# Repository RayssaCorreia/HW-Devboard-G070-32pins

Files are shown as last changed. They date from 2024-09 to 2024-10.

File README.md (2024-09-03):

# Devboard-G070-32pins
Jornada de desenvolvimento  

### Softwares, ferramentas e tecnologias utilizadas para o projeto

- [Git](https://git-scm.com/) - Controlamento de versionamento 
- [Github](https://github.com/) - Compartilhamento do Projeto 
- [Kicad](https://docs.kicad.org/) - Software de desenvolvimento da PCB 
- [STM32 Cube IDE](https://www.st.com/en/development-tools/stm32cubeide.html) - Software de programação
- [Arduino](https://docs.arduino.cc/hardware/uno-rev3/) - Exemplos e talves gravação via a sua IDE
- [Flatcom](http://flatcam.org/manual/installation.html#linux)
- [CNC Router 3018 Pro 200W](https://router66.com.br/produto/cnc-router-3018-pro-200w/) - maquina para prototipagem da placa
### Comparação entre os pinos do Arduino Uno e o micro stm32g070

### Arduino
- Analog pins 

  | Pin | Function    | Type           | Description                 |
  |-----|-------------|----------------|-----------------------------|
  | 1   | NC          | NC             | Not connected               |
  | 2   | IOREF       | IOREF          | Reference for digital logic V - connected to 5V |
  | 3   | Reset       | Reset          | Reset                       |
  | 4   | +3V3        | Power          | +3V3 Power Rail             |
  | 5   | +5V         | Power          | +5V Power Rail              |
  | 6   | GND         | Power          | Ground                      |
  | 7   | GND         | Power          | Ground                      |
  | 8   | VIN         | Power          | Voltage Input               |
  | 9   | A0          | Analog/GPIO    | Analog input 0 / GPIO       |
  | 10  | A1          | Analog/GPIO    | Analog input 1 / GPIO       |
  | 11  | A2          | Analog/GPIO    | Analog input 2 / GPIO       |
  | 12  | A3          | Analog/GPIO    | Analog input 3 / GPIO       |
  | 13  | A4/SDA      | Analog input/I2C | Analog input 4 / I2C Data line |
  | 14  | A5/SCL      | Analog input/I2C | Analog input 5 / I2C Clock line |

- Digital pins 

  | Pin | Function        | Type             | Description                                  |
  |-----|-----------------|------------------|----------------------------------------------|
  | 1   | D0              | Digital/GPIO     | Digital pin 0 / GPIO                         |
  | 2   | D1              | Digital/GPIO     | Digital pin 1 / GPIO                         |
  | 3   | D2              | Digital/GPIO     | Digital pin 2 / GPIO                         |
  | 4   | D3              | Digital/GPIO     | Digital pin 3 / GPIO                         |
  | 5   | D4              | Digital/GPIO     | Digital pin 4 / GPIO                         |
  | 6   | D5              | Digital/GPIO     | Digital pin 5 / GPIO                         |
  | 7   | D6              | Digital/GPIO     | Digital pin 6 / GPIO                         |
  | 8   | D7              | Digital/GPIO     | Digital pin 7 / GPIO                         |
  | 9   | D8              | Digital/GPIO     | Digital pin 8 / GPIO                         |
  | 10  | D9              | Digital/GPIO     | Digital pin 9 / GPIO                         |
  | 11  | SS              | Digital SPI      | Chip Select                                  |
  | 12  | MOSI            | Digital SPI1     | Main Out Secondary In                        |
  | 13  | MISO            | Digital SPI      | Main In Secondary Out                        |
  | 14  | SCK             | Digital SPI      | Serial clock output                          |
  | 15  | GND             | Power            | Ground                                       |
  | 16  | AREF            | Digital          | Analog reference voltage                     |
  | 17  | A4/SD4          | Digital          | Analog input 4 / I2C Data line (duplicated)  |
  | 18  | A5/SD5          | Digital          | Analog input 5 / I2C Clock line (duplicated) |

### [STMG070KBT6](https://www.st.com/resource/en/datasheet/stm32g070rb.pdf)

| Pin Number | Pin Name (function upon reset) | Alternate Functions |
|---|---|---|
| 1 | PB9 | IR_OUT, TIM17_CH1, USART3_RX, SPI2_NSS, I2C1_SDA, EVENTOUT |
| 2 | PC14- OSC32_IN (PC14) | TIM1_BKIN2 |
| 3 | PC15- OSC32_OUT (PC15) | OSC32_EN, OSC_EN, TIM15_BKIN |
| 4 | VDD/VDDA | - |
| 5 | VSS/VSSA | - |
| 6 | NRST | - |
| 7 | PA0 | SPI2_SCK, USART2_CTS, USART4_TX |
| 8 | PA1 | SPI1_SCK/I2S1_CK, USART2_RTS_DE_CK, USART4_RX |
| 9 | PA2 | SPI1_MOSI/I2S1_SD, USART2_TX, TIM15_CH1 |
| 10 | PA3 | SPI2_MISO, USART2_RX, TIM15_CH2, EVENTOUT |
| 11 | PA4 | SPI1_NSS/I2S1_WS, SPI2_MOSI, TIM14_CH1, EVENTOUT |
| 12 | PA5 | SPI1_SCK/I2S1_CK, USART3_TX, EVENTOUT |
| 13 | PA6 | SPI1_MISO/I2S1_MCK, TIM3_CH1, TIM1_BKIN, USART3_CTS, TIM16_CH1 |
| 14 | PA7 | SPI1_MOSI/I2S1_SD, TIM3_CH2, TIM1_CH1N, TIM14_CH1, TIM17_CH1 |
| 15 | PB0 | SPI1_NSS/I2S1_WS, TIM3_CH3, TIM1_CH2N, USART3_RX |
| 16 | PB1 | TIM14_CH1, TIM3_CH4, TIM1_CH3N, USART3_RTS_DE_CK, EVENTOUT |
| 17 | PB2 | SPI2_MISO, USART3_TX, EVENTOUT |
| 18 | PA8 | MCO, SPI2_NSS, TIM1_CH1, EVENTOUT |
| 19 | PA9 | MCO, USART1_TX, TIM1_CH2, SPI2_MISO, TIM15_BKIN, I2C1_SCL, EVENTOUT |
| 20 | PC6 | TIM3_CH1 |
| 21 | PA10 | SPI2_MOSI, USART1_RX, TIM1_CH3, TIM17_BKIN, I2C1_SDA, EVENTOUT |
| 22 | PA11 | SPI1_MISO/I2S1_MCK, USART1_CTS, TIM1_CH4, TIM1_BKIN2, I2C2_SCL |
| 23 | PA12 | SPI1_MOSI/I2S1_SD, USART1_RTS_DE_CK, TIM1_ETR, I2S_CKIN, I2C2_SDA |
| 24 | PA13 | SWDIO, IR_OUT, EVENTOUT |
| 25 | PA14-BOOT0 | SWCLK, USART2_TX, EVENTOUT |
| 26 | PA15 | SPI1_NSS/I2S1_WS, USART2_RX, USART4_RTS_DE_CK, USART3_RTS_DE_CK, EVENTOUT |
| 27 | PB3 | SPI1_SCK/I2S1_CK, TIM1_CH2, USART1_RTS_DE_CK, EVENTOUT |
| 28 | PB4 | SPI1_MISO/I2S1_MCK, TIM3_CH1, USART1_CTS, TIM17_BKIN, EVENTOUT |
| 29 | PB5 | SPI1_MOSI/I2S1_SD, TIM3_CH2, TIM16_BKIN, I2C1_SMBA |
| 30 | PB6 | USART1_TX, TIM1_CH3, TIM16_CH1N, SPI2_MISO, I2C1_SCL, EVENTOUT |
| 31 | PB7 | USART1_RX, SPI2_MOSI, TIM17_CH1N, USART4_CTS, I2C1_SDA, EVENTOUT |
| 32 | PB8 | SPI2_SCK, TIM16_CH1, USART3_TX, TIM15_BKIN, I2C1_SCL, EVENTOUT |

# 

<table>
<thead>
  <tr>
    <th colspan="2">Arduino</th>
    <th colspan="2">Stm32G070</th>
  </tr>
  <tr>
    <td>Bit 0</td>
    <td>Bit 1</td>
    <td>Bit 2</td>
    <td>Bit 3</td>
    <td>Bit 4</td>
    <td>Bit 5</td>
    <td>Bit 6</td>
    <td>Bit 7</td>
    <td>Bit 8</td>
    <td>Bit 9</td>
    <td>Bit 10</td>
    <td>Bit 11</td>
    <td>Bit 12</td>
    <td>Bit 13</td>
    <td>Bit 14</td>
    <td>Bit 15</td>
  </tr>
</thead>
<tbody>
  <tr>
    <th colspan="8">ff</th>
    <th colspan="8">01</th>
  </tr>
  <tr>
    <td colspan="9">        Heading GPS</td>
    <td> Acc</td>
    <td> Jammer</td>
    <td> GPS Status</td>
    <td> Power Supply Status</td>
    <td> Critical Battery</td>
    <td> Ignition</td>
    <td> Speed Value</td>
  </tr>
</tbody>
</table>

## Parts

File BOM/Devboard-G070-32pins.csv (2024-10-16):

Reference | Value | Datasheet | Footprint | Qty | DNP
BZ1 | Buzzer | ~ |  | 1
C2,C7,C11,C12 | 20pF | ~ |  | 4
C3,C5,C8 | 100nf | ~ |  | 3
C4 | 100uF | ~ |  | 1
C6 | 10uF | ~ |  | 1
C9,C10 | 100nF | ~ |  | 2
D1 | LED_RGB | ~ |  | 1
D2,D5 | TVS 5.0 | ~ |  | 2
D3 | LED_Red | ~ |  | 1
D4 | B5819W | ~ |  | 1
F1 | 1A | ~ |  | 1
IC1 | MC3479 | http://www.memsic.com/uploadfiles/2020/08/20200827164636363.pdf | MC3479 | 1
J1 | Conn_01x04 | ~ |  | 1
J2 | USB_C_Receptacle_USB2.0_16P | https://www.usb.org/sites/default/files/documents/usb_type-c.zip |  | 1
J4 | Conn_01x05 | ~ |  | 1
J5,J8 | Conn_01x08 | ~ |  | 2
J6 | Conn_01x06 | ~ |  | 1
J7 | Conn_01x10 | ~ |  | 1
J9,J11 | Conn_02x18 | ~ | -- mixed values -- | 2
JP1,JP2,JP3,JP4,JP8,JP9 | 2_Open | ~ | TestPoint:TestPoint_2Pads_Pitch5.08mm_Drill1.3mm | 6
JP10 | ~ | ~ | TestPoint:TestPoint_2Pads_Pitch5.08mm_Drill1.3mm | 1
Q3 | 2N7002H | http://www.diodes.com/assets/Datasheets/2N7002H.pdf | Package_TO_SOT_SMD:SOT-23 | 1
R1,R2,R3 | 1K | ~ |  | 3
R4,R5 | 1k | ~ |  | 2
R6,R21 | 100 | ~ |  | 2
R7,R9,R10,R13,R14 | 4.7k | ~ |  | 5
R8 | 1M | ~ |  | 1
R11,R12 | 0 | ~ |  | 2
R20 | 100K | ~ |  | 1
SW3,SW4 | SW_MEC_5E | http://www.apem.com/int/index.php?controller=attachment&id_attachment=1371 |  | 2
U2 | TLV70233_SOT23-5 | http://www.ti.com/lit/ds/symlink/tlv702.pdf | Package_TO_SOT_SMD:SOT-23-5 | 1
U3 | STM32G070KBTx | https://www.st.com/resource/en/datasheet/stm32g070kb.pdf | Package_QFP:LQFP-32_7x7mm_P0.8mm | 1
Y1 | 32.768Khz | ~ |  | 1
Y2 | 8Mhz | ~ |  | 1

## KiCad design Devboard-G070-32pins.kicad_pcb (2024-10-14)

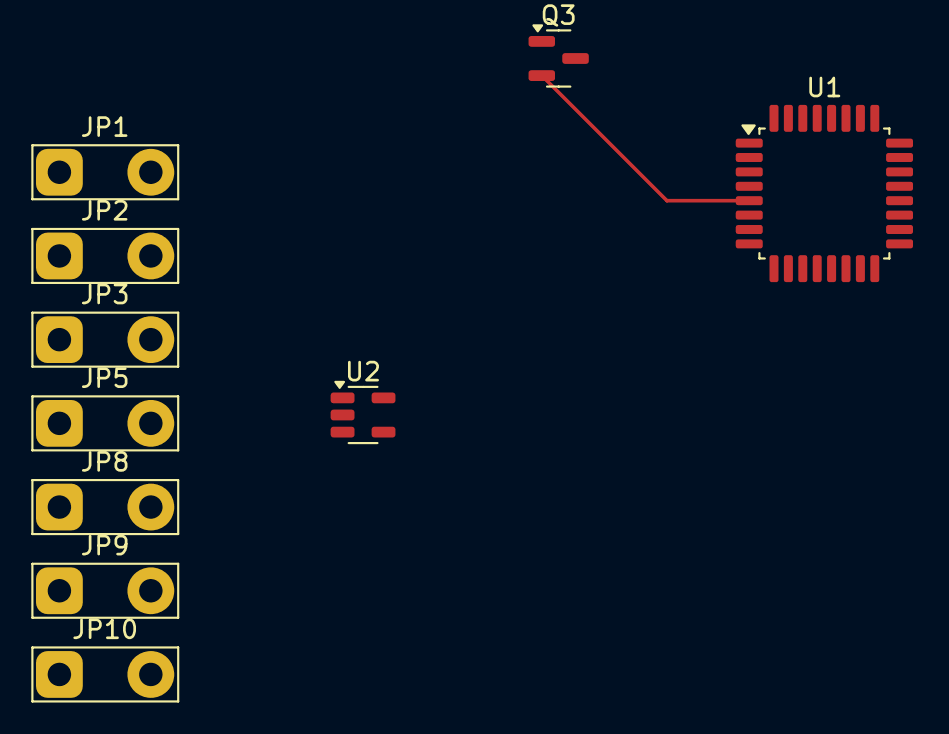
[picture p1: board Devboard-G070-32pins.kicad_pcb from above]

Board: 2 copper layers, 10 parts (0 on the bottom side), 9 nets.

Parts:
JP1, JP2, JP3, JP5, JP8, JP9: 2_Open; TestPoint_2Pads_Pitch5.08mm_Drill1.3mm
JP10: TestPoint_2Pads_Pitch5.08mm_Drill1.3mm
Q3: 2N7002H; SOT-23
U1: STM32G070KBTx; LQFP-32_7x7mm_P0.8mm
U2: TLV70233_SOT23-5; SOT-23-5

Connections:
+3V3: U1.4 (VDD), U2.5 (OUT)
BTN_Code: JP5.2 (B), U1.16 (PB1)
GND: Q3.2 (S), U1.5 (VSS), U2.2 (GND)
I2C_SCL: JP9.2 (B), U1.32 (PB8)
I2C_SDA: JP8.2 (B), U1.31 (PB7)
LED_B: JP3.2 (B), U1.21 (PA10/NC)
LED_G: JP2.2 (B), U1.19 (PA9/NC)
LED_R: JP1.2 (B), U1.18 (PA8)
USB_VBUS: JP10.1 (A), U2.1 (IN), U2.3 (EN)

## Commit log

2024-08-28 :heavy_plus_sign: added files of projecto kicad
    [Devboard-G070-32pins.kicad_pcb, Devboard-G070-32pins.kicad_sch, ExtensionConnectors.kicad_sch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]
2024-08-28 :construction: removing v1 folder
    [Devboard-G070-32pins.kicad_pcb, Devboard-G070-32pins.kicad_sch, ExtensionConnectors.kicad_sch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]
2024-09-03 schematic update
    [Devboard-G070-32pins.kicad_pcb, Devboard-G070-32pins.kicad_sch, ExtensionConnectors.kicad_sch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]
2024-10-14 update schematic
    [Devboard-G070-32pins.kicad_pcb, ExtensionConnectors.kicad_sch]
2024-10-16 [test] BOM
    [Devboard-G070-32pins.csv, ExtensionConnectors.kicad_sch, code.kicad_sch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]
2024-10-20 [bug] added gnd
    [code.kicad_sch]
